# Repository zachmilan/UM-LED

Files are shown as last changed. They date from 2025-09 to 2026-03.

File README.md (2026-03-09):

# UM-LED

UM-LED is a personal embedded systems project I am currently developing. The main idea is to build a cool remote control LED display (in the shape of the University of Michigan's "M") for my desk. This will be done by designing two PCB's - the remote and the display - and writing the firmware for each.

### Project Status 

March 9, 2026: The remote is complete and the firmware is in a consistent working state. Capacitive touch, BLE, haptics, motion detection, sleep timeout, charging and charging indicators, and low battery indicator all function as intended and have been integrated as a system. Changes to the remote's firmware will likely be made once the display is built and integrated, along with a few other polishing touches. Next step is the display PCB schematic. 

This is the first (and hopefully only) version of the remote PCB. Assembly was done using a stencil + hot-plate as well as hand soldering for necessary parts. Some rework and debugging was involved. 

Features, photos, and two short demo videos of the assembled remote exist below.

### Remote Features:
* **Capacitive Touch Pads:** Used for easy brightness control.
* **Accelerometer:** Automatically wakes the remote when picked up.
* **Haptic Motor:** Provides clear tactile feedback for user interactions.
* **USB-C Rechargeable:** Self explanatory, but easily charged with a USB-C cord and indicates charging status via lights.
* **Low Battery Indication:** Red light informs user when remote needs to be charged.
  
| Top View | Bottom View |
| :---: | :---: |
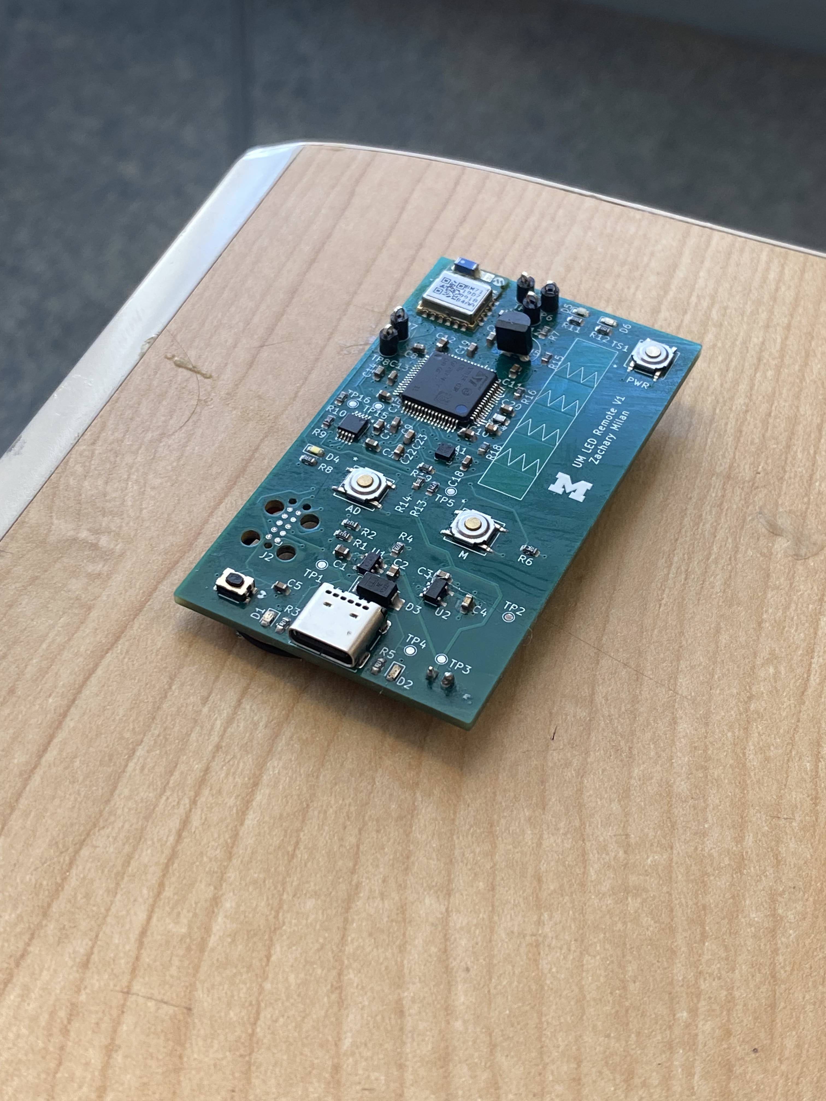
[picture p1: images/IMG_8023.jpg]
UM-LED Remote Top View
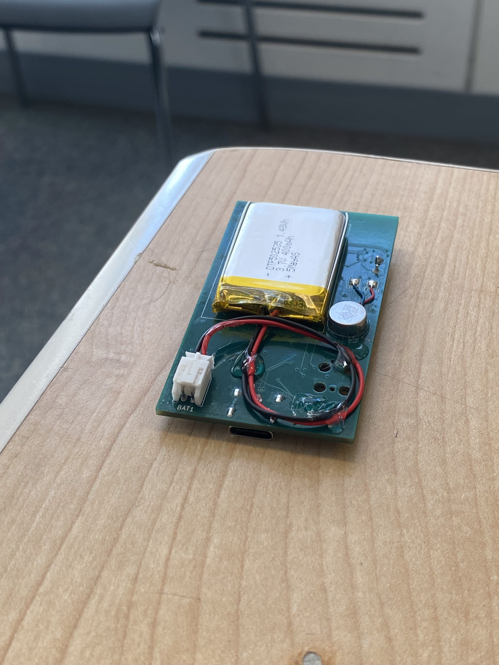
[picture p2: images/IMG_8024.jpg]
UM-LED Remote PCB Detail
|  |  |
| *The top contains the hardware and UI* | *The underside contains the battery and haptic motor (hot-glued)* |

<div align="center">

**Capacitive Touch Demo**

https://github.com/user-attachments/assets/bd866a0d-1efd-45fc-9129-0372a43028ab

*Each touch triggers an LED flash and haptic feedback (turn volume UP to hear haptics firing).*

**Remote Sleep Demo**

https://github.com/user-attachments/assets/c11abb02-e6e1-4325-9b7a-56cc4e109a6d

*The remote wakes upon movement, and falls back asleep after 10 seconds of inactivity.*

</div>

---

### More details
I wrote a full, more formal design proposal when beginning this project — see [UM-LED Design Proposal (PDF)](https://github.com/zachmilan/UM-LED/blob/main/docs/UM-LED%20Design%20Proposal%20(No%20Timeline).pdf). The main idea is still intact, though it may not reflect the full design once done (for example, the accelerometer was an afterthought and hence not included in the proposal).

Or, if you just want to get an idea of the general system architecture, see below: 

| Remote Architecture | Display Architecture |
| :---: | :---: |
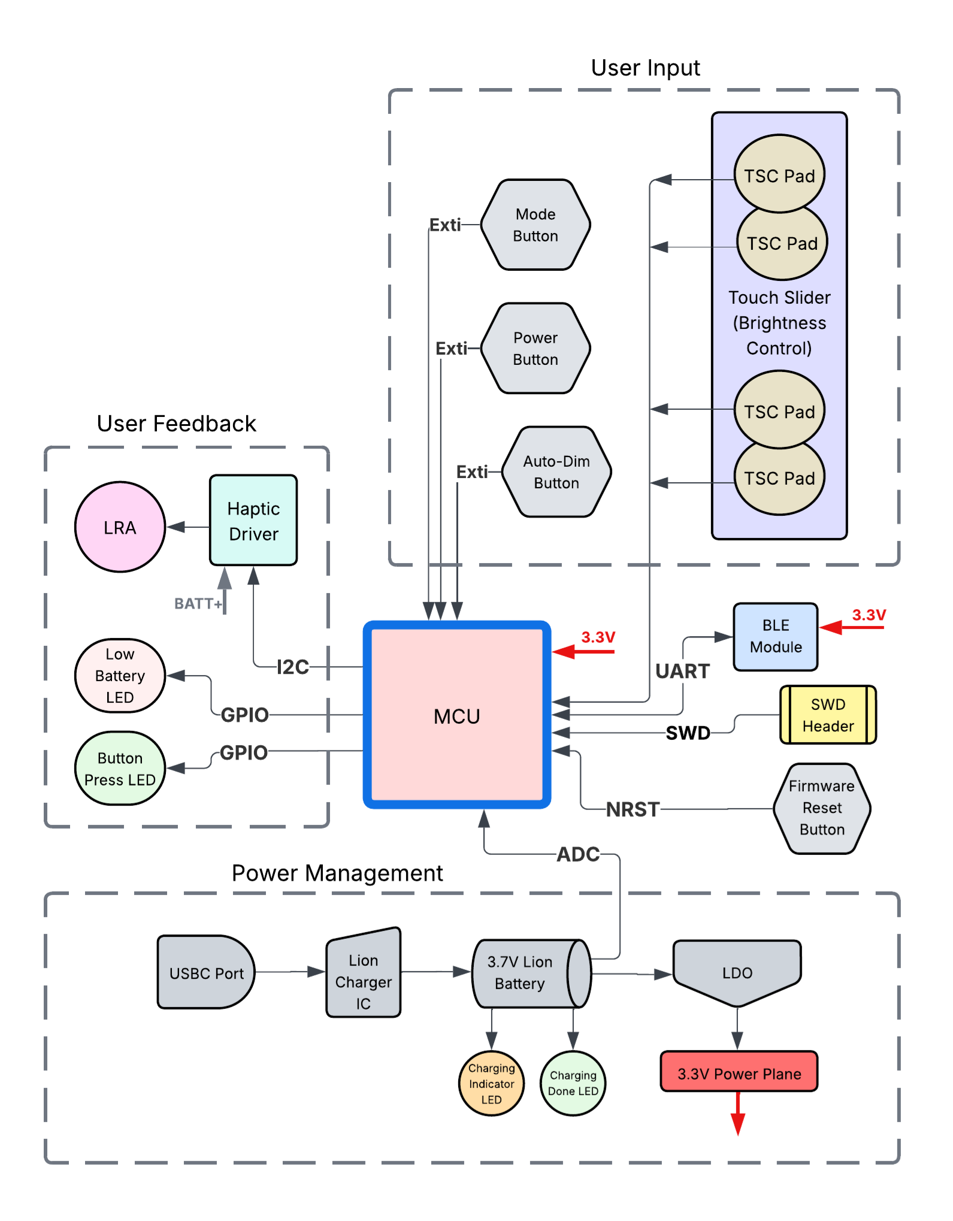
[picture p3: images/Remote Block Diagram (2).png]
UM-LED Remote Architecture
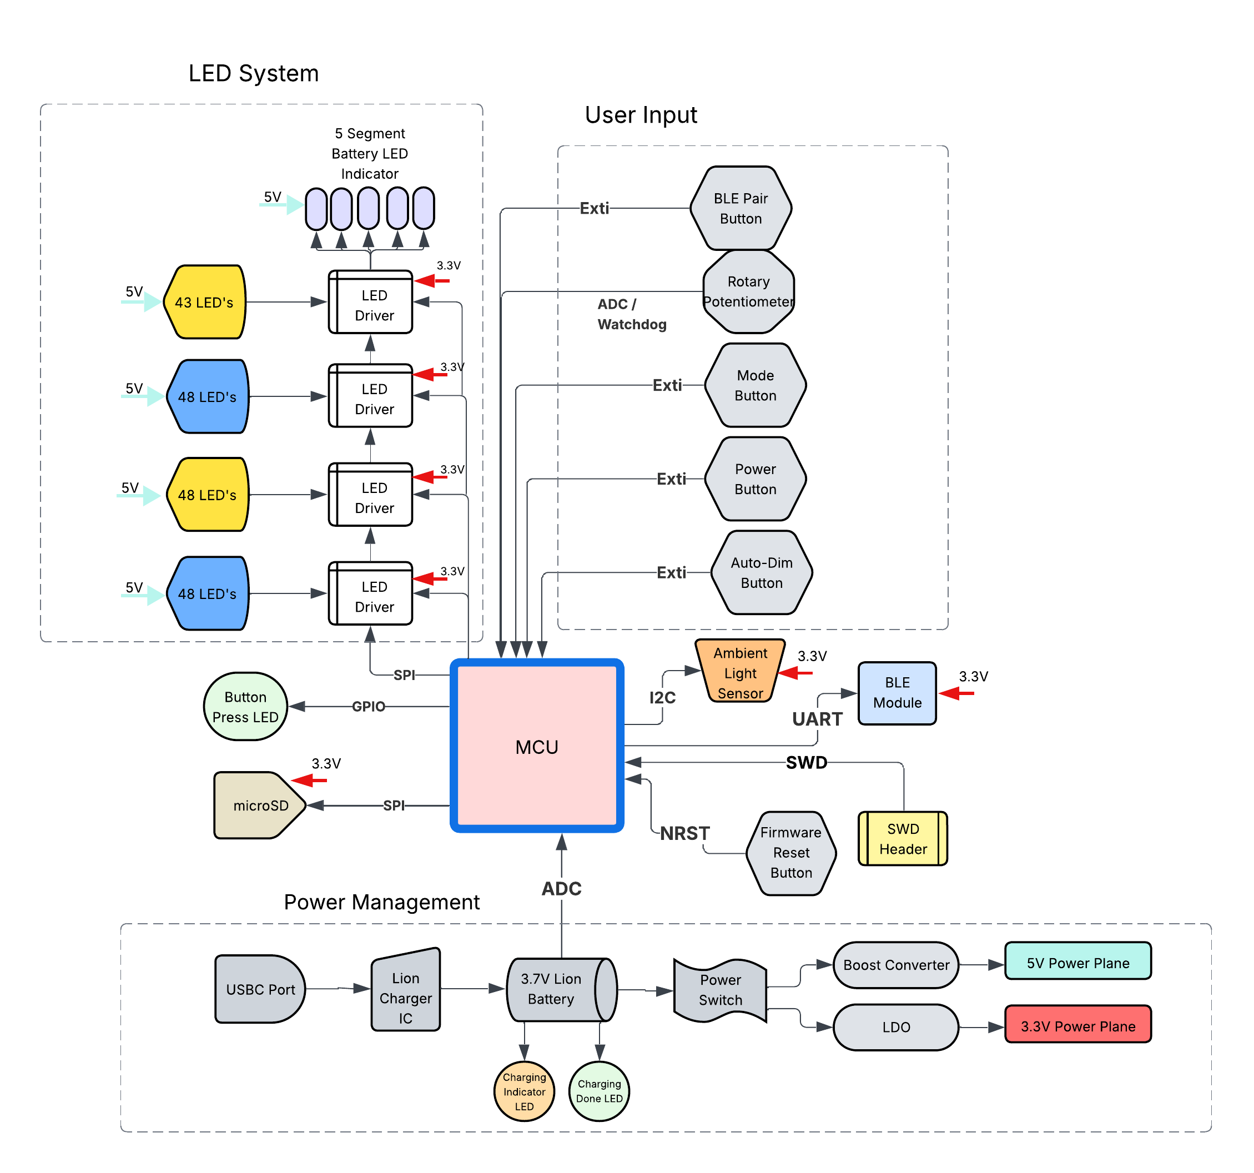
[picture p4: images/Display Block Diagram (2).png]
UM-LED Display Architecture
|  |  |
| *Signal flow for the remote, including the MCU, sensors, and haptic feedback.* | *System architecture for the LED display, including MCU, sensors, and power regulation.* |

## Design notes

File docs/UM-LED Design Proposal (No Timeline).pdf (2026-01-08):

Zachary Milan

UM-LED Design Proposal

This document outlines the planned design and functionality of UM-LED during its early design phase, prior to detailed PCB design, hardware assembly, and firmware implementation. It serves as a proposal for the intended system and the project is subject to change during development.

### 1. Project Overview

UM-LED is a remote-controlled LED display in the shape of the University of Michigan’s Block-M, intended to be a visually striking addition to a room or workspace. The system resembles a consumer product, offering features such as adjustable brightness, multiple LED modes, auto-dimming, and rechargeability. The display rests on a flat surface, supported in an upright position by an attached stand.

The project consists of two parts:

- LED display – a Block-M configuration of individually-controlled LEDs, capable of displaying a variety of patterns with varying brightness.
- Remote Control – a handheld controller with tactile feedback that allows users to wirelessly toggle power, cycle through modes, and adjust brightness of the display.

Together, the display and remote create an interactive device that feels polished, responsive, and fun to use.

### 2. Concept and Purpose

UM-LED is inspired by my pride for the University of Michigan (Go Blue!) and the desire to create something unique for my workspace. At the same time, it serves as a platform to sharpen my embedded systems skills by taking a mere idea through the entire development process, from concept and planning, to PCB schematic and layout, to firmware and mechanical integration, finishing with a polished, consumer-style product.

The design draws from consumer products I admire and use regularly, such as Apple’s use of capacitive touch and haptic feedback, and the simplicity of my rechargeable wireless speaker. These influences shape both the system's interface and the overall user experience.

Figure 1 shows early concept art of UM-LED, illustrating the Block-M display and associated remote, highlighting the consumer-style appearance with simple, intuitive user interfaces for each.

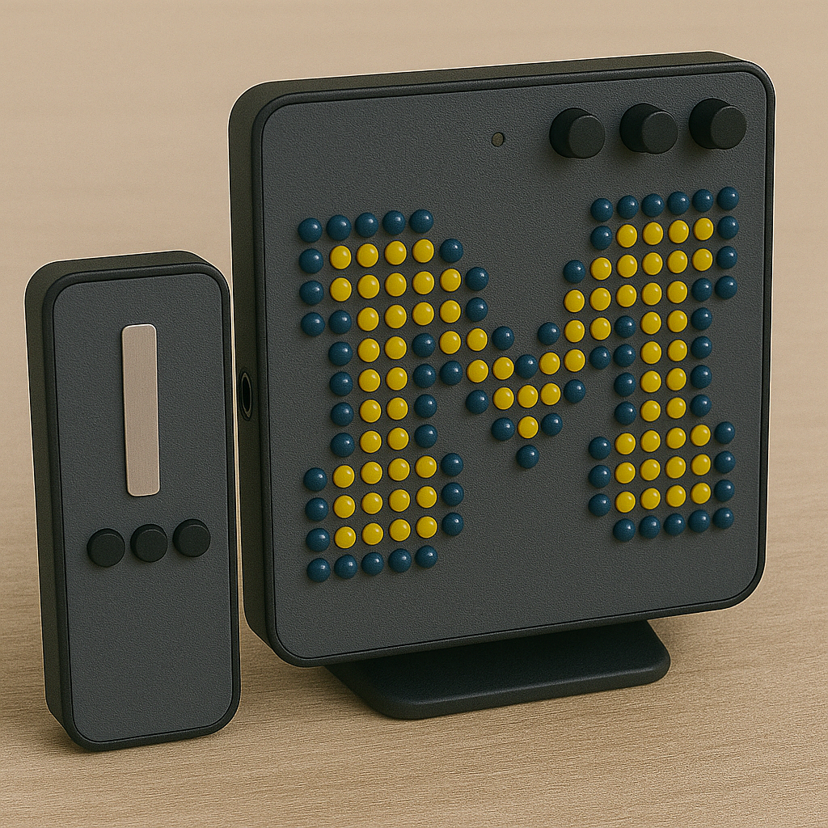
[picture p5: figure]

Figure 1: Rough Concept Art of UM-LED

### 3. System Features

UM-LED includes several features across both the remote and display that enhance the user experience and make the system unique.
Remote Control
- Wireless control of LED display via Bluetooth Low Energy (BLE)
- Brightness control via a capacitive-touch slider
- Haptic feedback upon brightness adjustments
- Mode, power, and auto-dim buttons
- Status indicators for charging, low battery, and button presses
- Rechargeable via USB-C
LED Display
- Through-hole LEDs arranged in the Block-M pattern (yellow fill, blue outline)
- Cyclable LED patterns/modes (heartbeat, snake, demo cycle, etc.)
- Local mode, power, and auto-dim buttons
- Local brightness control via rotating knob
- Status indicators for charging, battery level, auto-dim mode, and button presses
- Rechargeable via USB-C
- A microSD card for logging the display’s power usage over time

### 4. Functional Requirements

UM-LED’s functional requirements are listed below, and are achieved through a combination of component selection, hardware design, and firmware optimizations.
Remote Control
- Recharge time: ≤ 5 hours via USB-C
- Battery life: ≥ 1 week per charge under normal use
- BLE range: 3-5m indoors
- Haptic feedback latency: ≤ 100ms
- Brightness control: ≥ 20 levels
Display
- Recharge time: ≤ 10 hours via USB-C
- Battery life: ≥ 1 week per charge under normal use
- Supports ≥ 5 LED animation modes
- Restores last brightness and mode on startup System Level
- Automatic BLE reconnection after sleep/wake cycle
- Remote inputs update the display within 200ms
- Power usage data is automatically stored when microSD card is present

### 5. System Architecture

The UM-LED system is implemented on two custom printed circuit boards (PCBs) – the display and the remote. Each PCB consists of its own microcontroller, dedicated power system, and necessary peripherals to provide the intended features and functionality.

Remote Architecture
The remote PCB is built around an STM32 microcontroller and integrates multiple user input and feedback features. Brightness is adjusted using a capacitive touch slider implemented through the STM32’s native TSC peripheral, while dedicated tactile pushbuttons provide mode, power, and auto-dim control. A linear resonant actuator (LRA), driven by a haptic driver IC, delivers haptic feedback during brightness adjustments. Wireless communication with the display is handled by a BLE module, and a reset button and SWD header are included for firmware development and debugging. Additional user feedback includes LED indicators for button presses, low battery, and charging status.

Power is supplied by a single-cell 3.7V Li-ion battery, rechargeable via a USB-C receptacle and dedicated charging IC. The battery powers a 3.3V rail – regulated by an LDO – and the haptic driver directly. Figure 2 illustrates the remote’s full architecture.

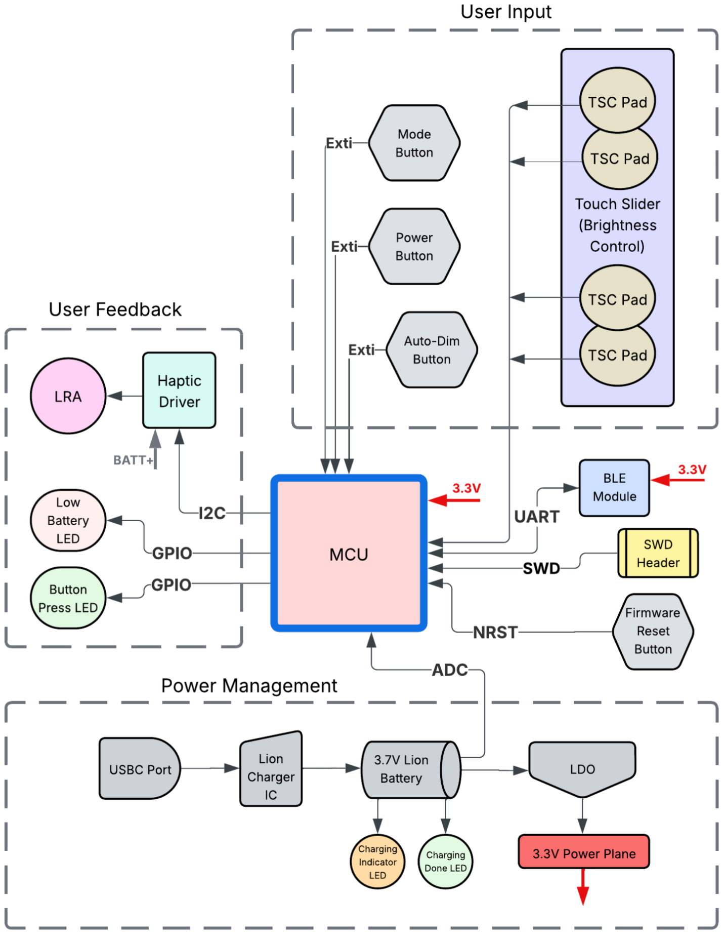
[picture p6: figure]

Figure 2: Remote PCB System Architecture

Display Architecture
The display PCB is built around an STM32 microcontroller and drives the Block-M LED configuration through daisy-chained constant-current LED drivers. Local user input is provided by pushbuttons (mode, power, auto-dim) and a rotary potentiometer for brightness adjustment via ADC readings. An ambient light sensor supports automatic dimming functionality. Wireless control is handled by a BLE module – receiving control data from the remote – and a microSD card slot is included for power-usage logging. A 5-segment LED bar indicates battery status, while other LED indicators exist for button presses and charging status.

Power is supplied by a single-cell 3.7V Li-ion battery, rechargeable via a USB-C receptacle and dedicated charger IC. The battery supplies two voltage rails – a 5V rail via a boost converter (powering the LED configuration), and a 3.3V rail via an LDO for the MCU and peripheral circuitry. A power switch exists to completely cut battery power to the system. Figure 3 illustrates the display’s full architecture.

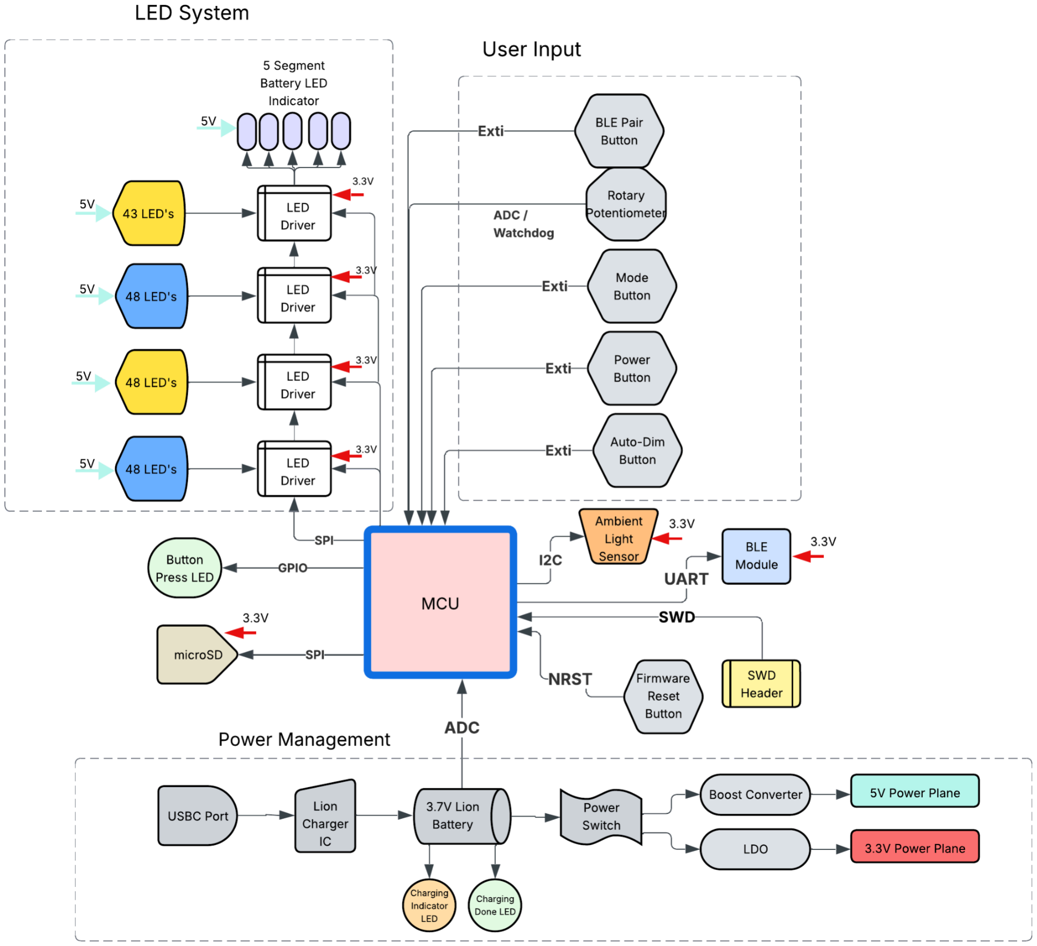
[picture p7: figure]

Figure 3: Display PCB System Architecture

### 7. Major Components

Table 1 lists major components and their functionality and usage across the remote and display boards. Table 1: Major Components

Component | Description & Functionality | Used In
STM32F303RCT6 MCU | Microcontroller for both remote and display boards; chosen for high pin count, built-in TSC peripheral, and variety of serial communication peripherals. | Remote, Display
IS31FL3248 LED Driver | 48-channel constant-current-sink LED driver IC. Chosen for high channel count, SPI interface, and constant-current capability. | Display
BM71BLES1FC2 BLE Module | BLE module for both remote and display. Chosen for its on-board antenna, UART interface, auto-operation feature, and configurable GPIOs. | Remote, Display
DRV2605L Haptic Driver | Haptic driver IC to control LRA for haptic feedback. Chosen for its I2C interface and built-in haptic effects library. | Remote
MCP73831 Linear Charge Controller | Linear charge management controller for remote’s Li-ion battery. Chosen for its simplicity and ease-of-use, as well as programmable charge current and charge status pin. | Remote
MAX77715 Autonomous USB-C Charger | Charge management controller for display’s Li-ion battery. Chosen for its fast charge current, automatic power source detection, and automatic input-current limit configuration. | Display
TLV755P LDO | Low-dropout regulator to supply 3.3V rails. Chosen for its popularity and simplicity, and reliability in a past project. | Remote, Display
MP3432 Boost Converter | Synchronous boost converter to supply 5V rail on the display. Chosen for its capability to output a high amount of current. | Display
VG0832013D LRA | Linear resonant actuator providing haptic feedback on the remote. Chosen for its small profile and popularity. | Remote

### 8. Implementation Details

Remote Firmware
Capacitive Touch Slider – The STM32’s TSC peripheral samples touch pads simultaneously. Values are smoothed/averaged, extreme readings mitigated, and the final result mapped to a discrete brightness level.

Buttons – Mode, power, auto-dim buttons generate interrupts upon press. Button debouncing and long-press detection occur in software.

Haptic Feedback – A linear resonant actuator (LRA) is driven by a dedicated haptic driver IC, controlled by the STM32 via I2C and a TRIG pin. The TRIG pin activates a predetermined haptic effect, occurring in sync with brightness changes sent over BLE.

BLE – The BLE modules function in “Auto-Operation” mode, acting as a UART bridge between boards for transmitting control data such as brightness, mode, auto-dim, and power.
Display Firmware
LED Control – The LED drivers are initialized and controlled via SPI. Each of the driver’s 48 channels is controlled individually via PWM registers, allowing for flexible patterns and a wide range of brightness. Multiple drivers are daisy-chained to support a high number of LEDs. Additionally, enabling the BLANK pin allows for immediate shutoff of all LEDs connected to a driver.

Local Controls – Similar to the remote, buttons on the display provide user access to mode, power, and auto-dim controls and generate interrupts upon press. Button debouncing and long-press detection occur in software. For brightness control, a rotary potentiometer provides an analog input, which firmware maps to a brightness scale for the display.

Ambient Light Sensor – In auto-dim mode, the display periodically takes readings from an ambient light sensor and updates global LED brightness accordingly.
Power Management
MCU Sleep/Wake – Both boards utilize low-power or sleep modes when idle, and wake upon user input or BLE events.

Battery Indicators – Voltage readings of the battery are taken via ADC. Firmware compares readings to determined thresholds and updates the display’s 5-segment bar or remote’s low-battery LED accordingly.

Charging – Charging ICs on both the remote and display handle safe battery charging without the need for firmware intervention.
Programming & Configuration
MCU Programming – The STM32 on both boards are programmed via SWD. Each board exposes SWD pins through a footprint compatible with a Tag-Connect cable connected to a ST-Link programmer.

BLE Configuration – The BLE modules are configured through UART using Microchip’s PC GUI tool. Low-profile test loops are provided on both boards to provide programming access for the module.

### 9. Proposed Physical Design

The proposed physical design of both the remote and display establishes the placement of user-interface elements in order to support preliminary STM32 pin-mapping and simplify PCB routing. These illustrations do not include all major components listed in Table 1, but emphasize user-interface and feedback elements that are given priority for pin assignments. Figures 4 and 5 illustrate the physical layout of the remote and display.

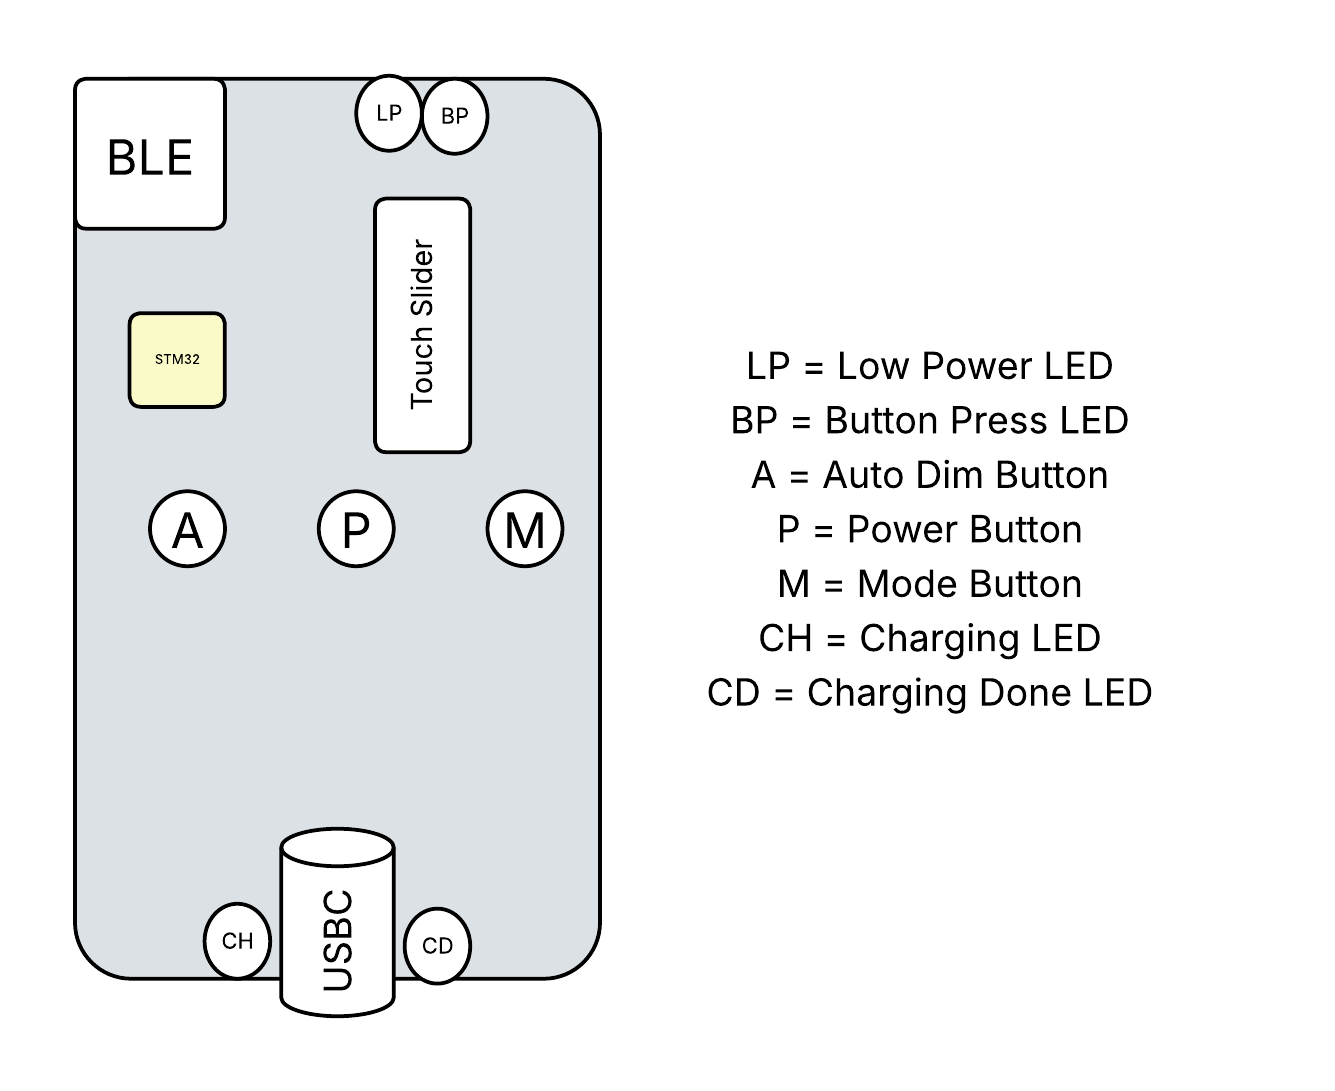
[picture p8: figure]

Figure 4: Remote Physical Layout

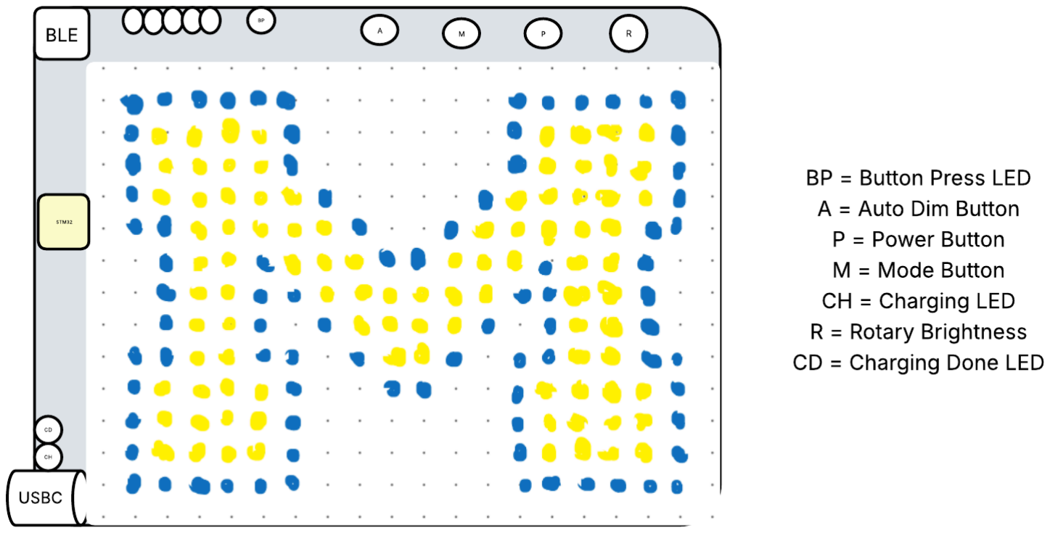
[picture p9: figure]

Figure 5: Display Physical Layout

### 10. Anticipated Technical Challenges

UM-LED involves several technical hurdles spanning hardware, firmware, wireless communication, and mechanical design. Table 2 details anticipated technical challenges along with a brief description of each. Table 2: Technical Challenges

Technical Challenge | Description
LED Driver Thermal Management | Managing heat dissipation from multiple constant-current LED drivers under high load (stemming from high brightness levels).
Switching Noise Suppression | Reducing switching noise from the boost converter and LED drivers on the display, which could interfere with serial communication and affect power integrity.
Reliable Wireless Communication | Ensuring automatic BLE reconnection between remote and display after waking, and achieving low-latency responses between remote user input and a display update.
Capacitive Touch Algorithm | Developing firmware to translate readings from a limited number of touch pads to numerous brightness levels and avoiding sudden jumps to extreme values.
MCU Power Management | Designing an efficient sleep/wake control flow for both boards in order to balance responsiveness during use with extended battery life when idle.
Power Logging to microSD Card | Implementing accurate and reliable logging of power usage data, including determining an appropriate sampling frequency and logging duration.
Mechanical Integration | Designing and producing polished 3D enclosures for both boards that expose the user interface and hide internal hardware.

### 11. Stretch Goals / Future Development

UM-LED has potential for several upgrades once the base system is complete. Extended functionality can be implemented through firmware updates, additional hardware, or both. Table 3 details possible stretch goals and a description for each.
Table 3: Stretch Goals
Stretch Goal | Description
Mobile Companion App | Develop a mobile app to control the display over BLE, offering an alternative to the physical remote and enabling extended control functionality.
Audio-sensitive LEDs | Add hardware and firmware to allow the display to react dynamically to ambient sound.
Battery Percentage Estimation | Provide a precise battery percentage readout on the display, potentially via a small LCD or OLED, instead of a 5-segment LED bar.
Extended Capacitive Slider Functions | Enable the remote’s capacitive slider to perform different actions depending on the mode (e.g. brightness adjustment and direct LED control)
Improved Mounting Options | Develop solutions for flexible mounting, such as wall brackets or magnetic attachments, in addition to the default stand.

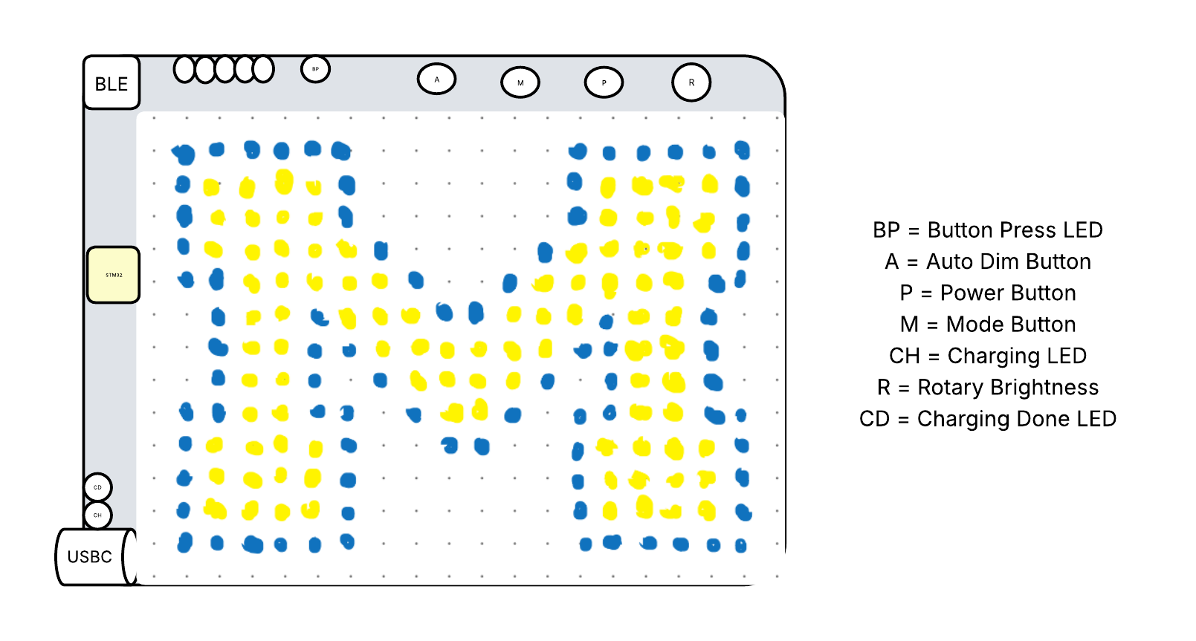
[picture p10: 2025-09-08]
images/Display Layout.png

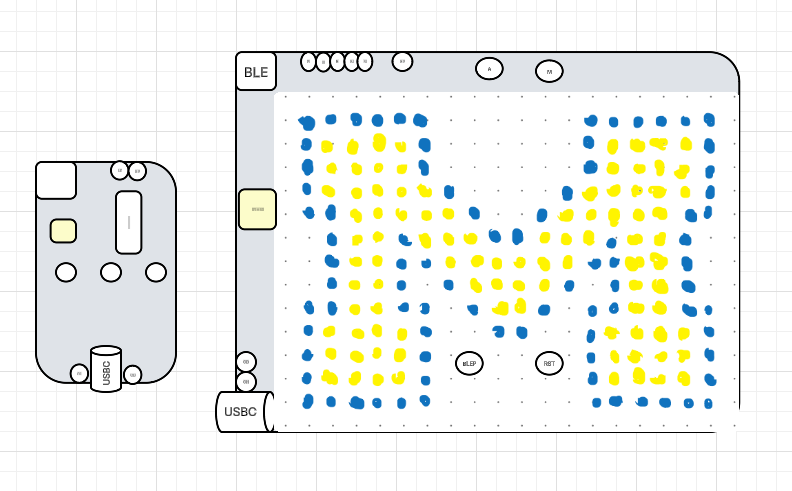
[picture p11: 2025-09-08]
images/Screenshot 2025-09-07 221949.png

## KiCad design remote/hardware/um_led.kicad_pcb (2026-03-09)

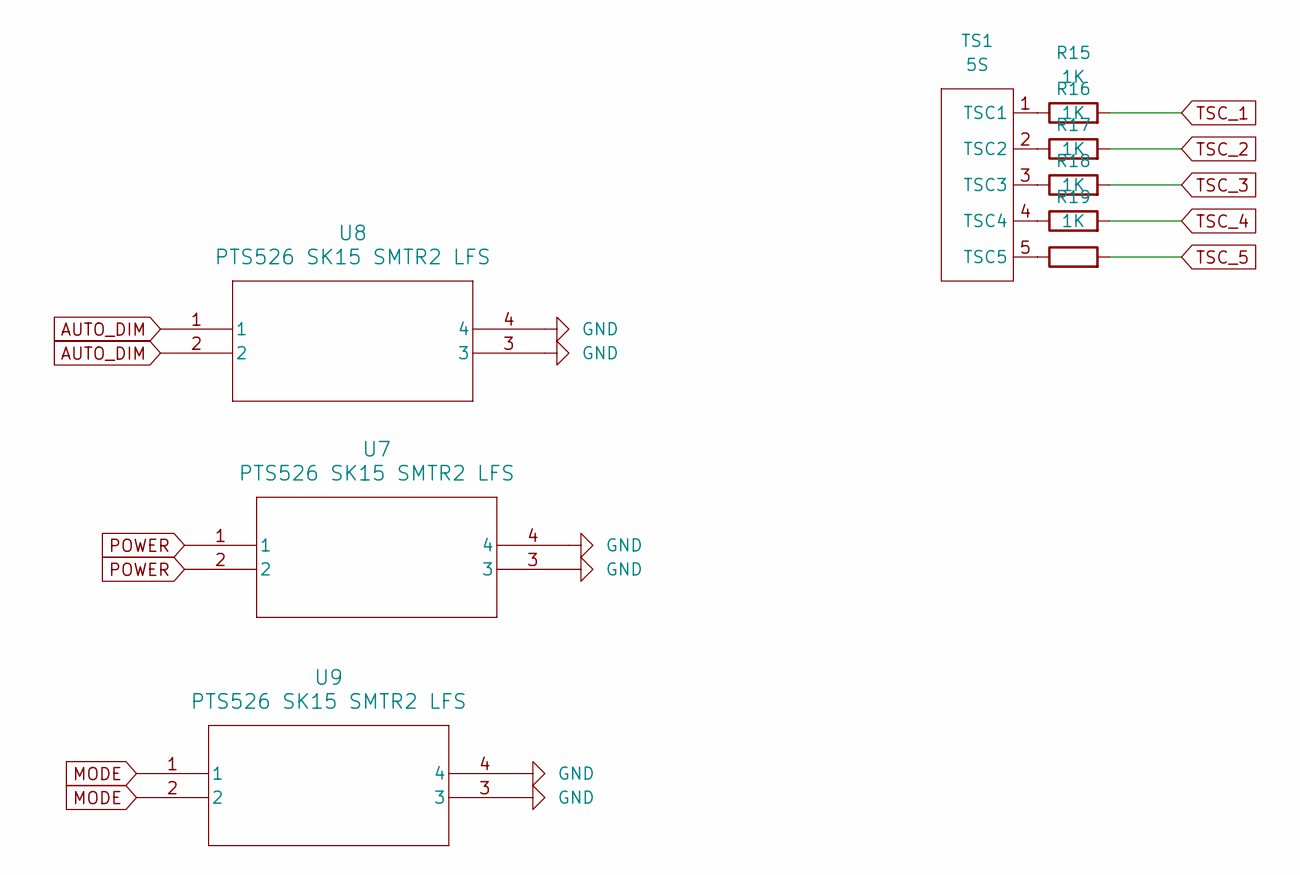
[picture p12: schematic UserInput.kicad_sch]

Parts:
R15, R16, R17, R18, R19: 1K; R_0603_1608Metric
TS1: 5S; TouchSlider-5_30x6mm
U7, U8, U9: PTS526 SK15 SMTR2 LFS; SMT_FS

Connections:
AUTO_DIM: U8.1, U8.2; also elsewhere on the board
GND: U7.3, U7.4, U8.3, U8.4, U9.3, U9.4; also elsewhere on the board
MODE: U9.1, U9.2; also elsewhere on the board
unnamed: R15.1, TS1.1 (TSC1)
unnamed: R16.1, TS1.2 (TSC2)
unnamed: R17.1, TS1.3 (TSC3)
unnamed: R18.1, TS1.4 (TSC4)
unnamed: R19.1, TS1.5 (TSC5)
POWER: U7.1, U7.2; also elsewhere on the board
TSC_1: R15.2; also elsewhere on the board
TSC_2: R16.2; also elsewhere on the board
TSC_3: R17.2; also elsewhere on the board
TSC_4: R18.2; also elsewhere on the board
TSC_5: R19.2; also elsewhere on the board

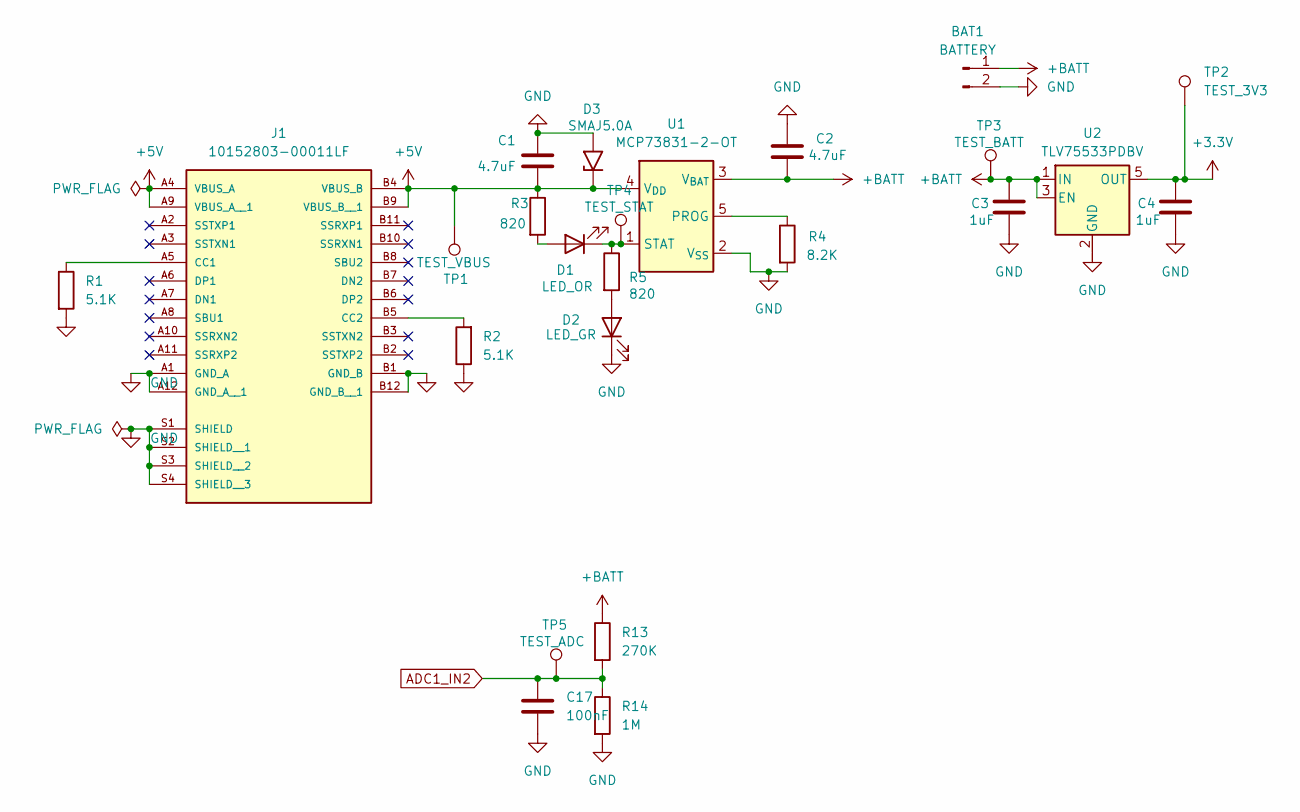
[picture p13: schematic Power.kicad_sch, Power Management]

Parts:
BAT1: BATTERY; JST_PH_S2B-PH-K_1x02_P2.00mm_Horizontal
C1, C2: 4.7uF; C_0603_1608Metric
C3, C4: 1uF; C_0603_1608Metric
C17: 100nF; C_0603_1608Metric
D1: LED_OR; LED_0603_1608Metric
D2: LED_GR; LED_0603_1608Metric
D3: SMAJ5.0A; D_SMA
J1: 10152803-00011LF; AMPHENOL_10152803-00011LF; PARTREV A
R1, R2: 5.1K; R_0603_1608Metric
R3, R5: 820; R_0603_1608Metric
R4: 8.2K; R_0603_1608Metric
R13: 270K; R_0603_1608Metric
R14: 1M; R_0603_1608Metric
TP1: TEST_VBUS; TestPoint_Pad_D1.0mm
TP2: TEST_3V3; TestPoint_Pad_D1.0mm
TP3: TEST_BATT; TestPoint_Pad_D1.0mm
TP4: TEST_STAT; TestPoint_Pad_D1.0mm
TP5: TEST_ADC; TestPoint_Pad_D1.0mm
U1: MCP73831-2-OT; SOT-23-5
U2: TLV75533PDBV; SOT-23-5

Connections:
+3.3V: C4.1, TP2.1, U2.5 (OUT); also elsewhere on the board
+5V: C1.2, D3.1 (A1), J1.A4 (VBUS_A), J1.A9 (VBUS_A__1), J1.B4 (VBUS_B), J1.B9 (VBUS_B__1), R3.1, TP1.1, U1.4 (V_{DD})
+BATT: BAT1.1, C2.2, C3.1, R13.1, TP3.1, U1.3 (V_{BAT}), U2.1 (IN), U2.3 (EN); also elsewhere on the board
ADC1_IN2: C17.1, R13.2, R14.1, TP5.1; also elsewhere on the board
GND: BAT1.2, C1.1, C2.1, C3.2, C4.2, C17.2, D2.1 (K), D3.2 (A2), J1.A1 (GND_A), J1.A12 (GND_A__1), J1.B1 (GND_B), J1.B12 (GND_B__1), J1.S1 (SHIELD), J1.S2 (SHIELD__1), J1.S3 (SHIELD__2), J1.S4 (SHIELD__3), R1.2, R2.1, R4.2, R14.2, U1.2 (V_{SS}), U2.2 (GND); also elsewhere on the board
unnamed: D1.2 (A), R3.2
unnamed: D1.1 (K), R5.1, TP4.1, U1.1 (STAT)
unnamed: D2.2 (A), R5.2
unnamed: J1.A5 (CC1), R1.1
unnamed: J1.B5 (CC2), R2.2
unnamed: R4.1, U1.5 (PROG)

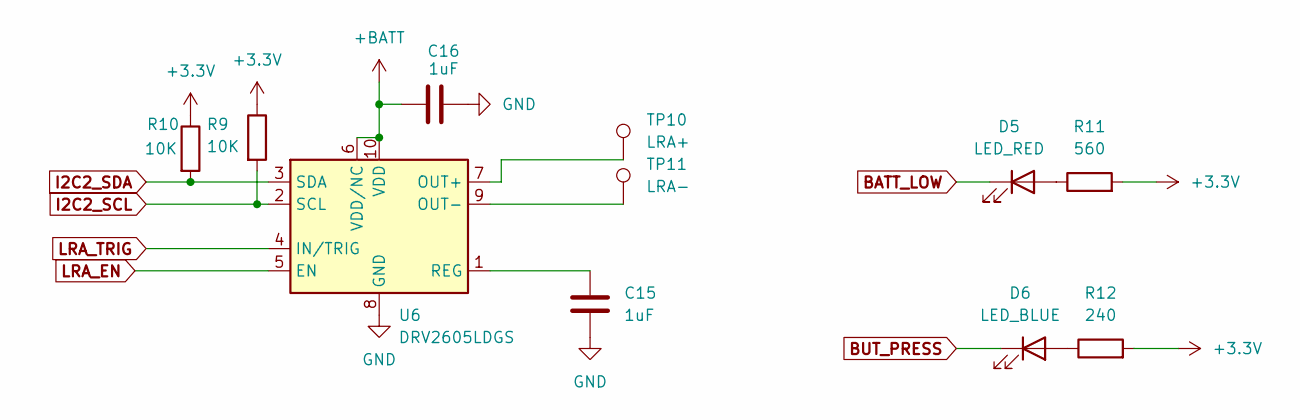
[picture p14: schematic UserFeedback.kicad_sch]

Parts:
C15, C16: 1uF; C_0603_1608Metric
D5: LED_RED; LED_0603_1608Metric
D6: LED_BLUE; LED_0603_1608Metric
R9, R10: 10K; R_0603_1608Metric
R11: 560; R_0603_1608Metric
R12: 240; R_0603_1608Metric
TP10: LRA+; TestPoint_Pad_2.0x2.0mm
TP11: LRA-; TestPoint_Pad_2.0x2.0mm
U6: DRV2605LDGS; VSSOP-10_3x3mm_P0.5mm

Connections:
+3.3V: R9.1, R10.1, R11.2, R12.2; also elsewhere on the board
+BATT: C16.2, U6.6 (VDD/NC), U6.10 (VDD); also elsewhere on the board
BATT_LOW: D5.1 (K); also elsewhere on the board
BUT_PRESS: D6.1 (K); also elsewhere on the board
GND: C15.1, C16.1, U6.8 (GND); also elsewhere on the board
I2C2_SCL: R9.2, U6.2 (SCL); also elsewhere on the board
I2C2_SDA: R10.2, U6.3 (SDA); also elsewhere on the board
LRA_EN: U6.5 (EN); also elsewhere on the board
LRA_TRIG: U6.4 (IN/TRIG); also elsewhere on the board
unnamed: D5.2 (A), R11.1
unnamed: D6.2 (A), R12.1
unnamed: TP10.1, U6.7 (OUT+)
unnamed: TP11.1, U6.9 (OUT-)
unnamed: C15.2, U6.1 (REG)

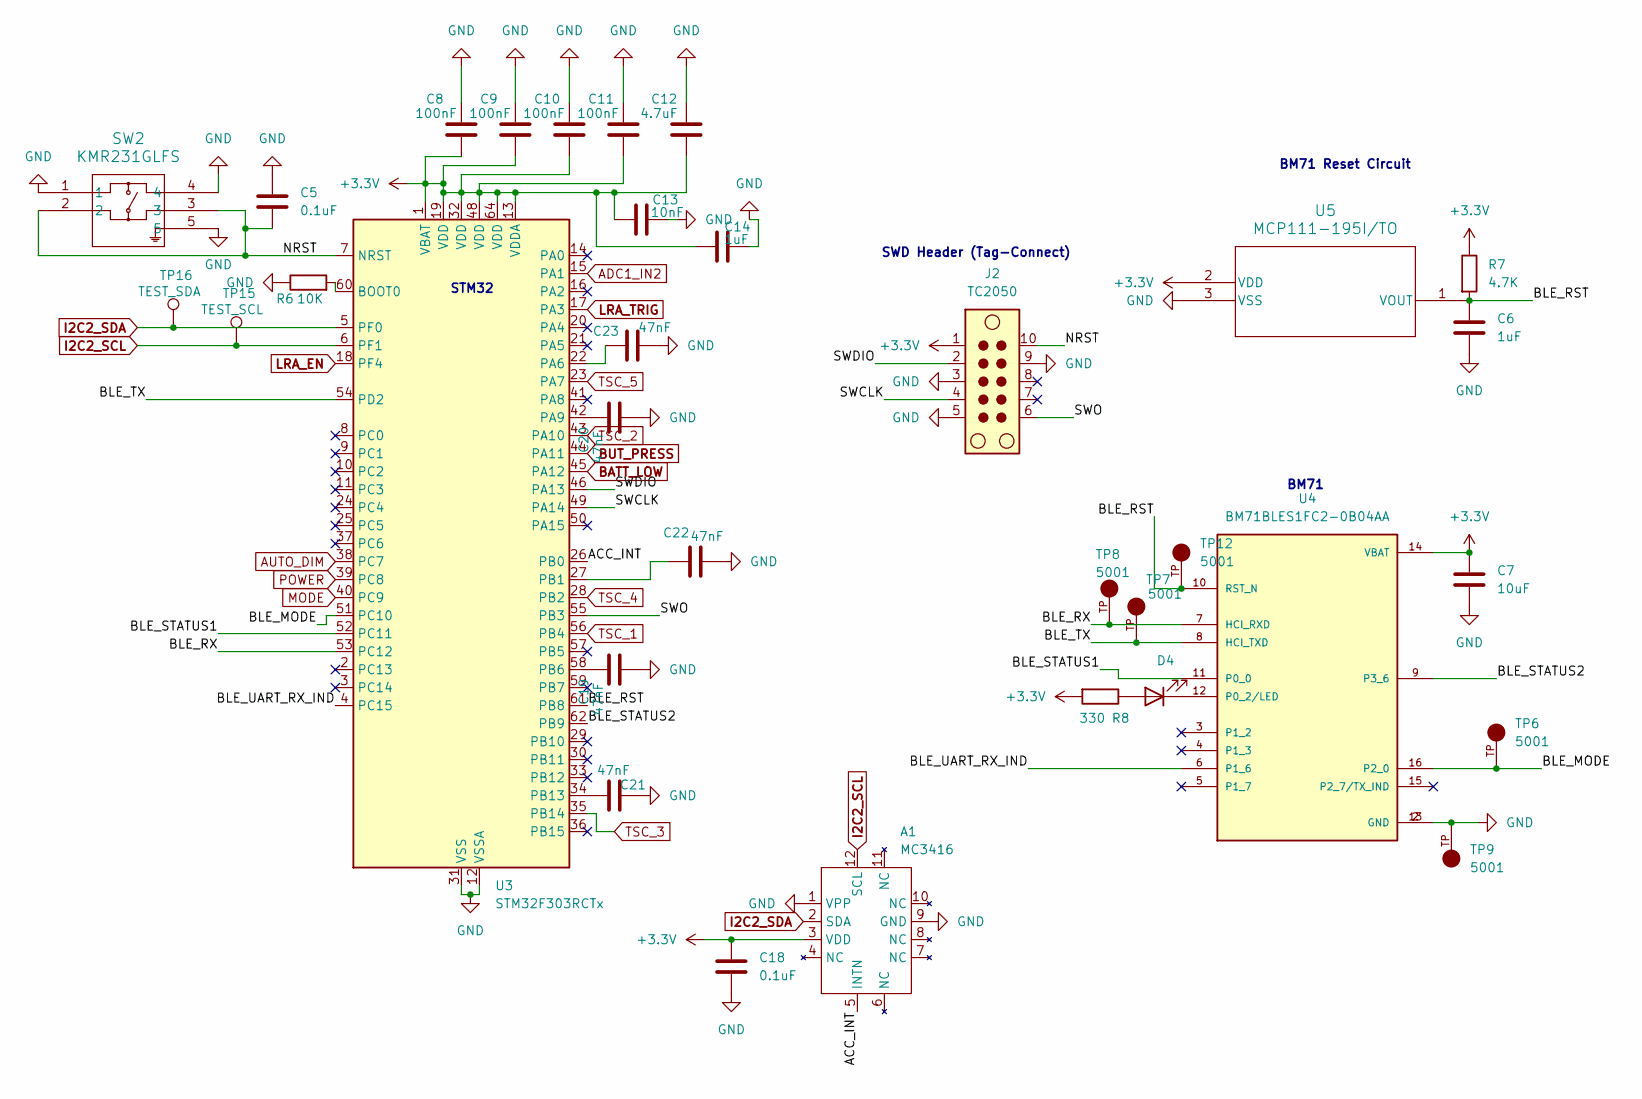
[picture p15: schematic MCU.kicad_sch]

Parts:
A1: MC3416; LGA-12_2x2mm_P0.5mm
C5, C18: 0.1uF; C_0603_1608Metric
C6, C14: 1uF; C_0603_1608Metric
C7: 10uF; C_0603_1608Metric
C8, C9, C10, C11: 100nF; C_0603_1608Metric
C12: 4.7uF; C_0603_1608Metric
C13: 10nF; C_0603_1608Metric
C19, C20, C21, C22, C23: 47nF; C_0603_1608Metric
D4: LED_WHITE; LED_0603_1608Metric
J2: TC2050; Tag-Connect_TC2050-IDC-FP_2x05_P1.27mm_Vertical
R6: 10K; R_0603_1608Metric
R7: 4.7K; R_0603_1608Metric
R8: 330; R_0603_1608Metric
SW2: KMR231GLFS; KMR2xxG_CNK
TP6, TP7, TP8, TP9, TP12: 5001; KEYSTONE_5001; PARTREV H; DigiKey_Part_Number 36-5001-ND
TP15: TEST_SCL; TestPoint_Pad_D1.0mm
TP16: TEST_SDA; TestPoint_Pad_D1.0mm
U3: STM32F303RCTx; LQFP-64_10x10mm_P0.5mm
U4: BM71BLES1FC2-0B04AA; XCVR_BM71BLES1FC2-0B04AA
U5: MCP111-195I/TO; TO-92_MC_MCH

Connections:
+3.3V: A1.3 (VDD), C7.1, C8.2, C9.2, C10.2, C11.2, C12.2, C13.1, C14.1, C18.1, J2.1, R7.1, R8.2, U3.1 (VBAT), U3.13 (VDDA), U3.19 (VDD), U3.32 (VDD), U3.48 (VDD), U3.64 (VDD), U4.14 (VBAT), U5.2 (VDD); also elsewhere on the board
/MCU/ACC_INT: A1.5 (INTN), U3.26 (PB0)
/MCU/BLE_MODE: TP6.TP, U3.51 (PC10), U4.16 (P2_0)
/MCU/BLE_RST: C6.1, R7.2, TP12.TP, U3.61 (PB8), U4.10 (RST_N), U5.1 (VOUT)
/MCU/BLE_RX: TP8.TP, U3.53 (PC12), U4.7 (HCI_RXD)
/MCU/BLE_STATUS1: U3.52 (PC11), U4.11 (P0_0)
/MCU/BLE_STATUS2: U3.62 (PB9), U4.9 (P3_6)
/MCU/BLE_TX: TP7.TP, U3.54 (PD2), U4.8 (HCI_TXD)
/MCU/BLE_UART_RX_IND: U3.4 (PC15), U4.6 (P1_6)
/MCU/NRST: C5.2, J2.10, SW2.2, SW2.3, U3.7 (NRST)
/MCU/SWCLK: J2.4, U3.49 (PA14)
/MCU/SWDIO: J2.2, U3.46 (PA13)
/MCU/SWO: J2.6, U3.55 (PB3)
ADC1_IN2: U3.15 (PA1); also elsewhere on the board
AUTO_DIM: U3.38 (PC7); also elsewhere on the board
BATT_LOW: U3.45 (PA12); also elsewhere on the board
BUT_PRESS: U3.44 (PA11); also elsewhere on the board
GND: A1.1 (VPP), A1.9 (GND), C5.1, C6.2, C7.2, C8.1, C9.1, C10.1, C11.1, C12.1, C13.2, C14.2, C18.2, C19.2, C20.2, C21.2, C22.2, C23.2, J2.3, J2.5, J2.9, R6.1, SW2.1, SW2.4, SW2.5, TP9.TP, U3.12 (VSSA), U3.31 (VSS), U3.47 (VSS), U3.63 (VSS), U4.2 (GND), U4.13 (GND), U5.3 (VSS); also elsewhere on the board
I2C2_SCL: A1.12 (SCL), TP15.1, U3.6 (PF1); also elsewhere on the board
I2C2_SDA: A1.2 (SDA), TP16.1, U3.5 (PF0); also elsewhere on the board
LRA_EN: U3.18 (PF4); also elsewhere on the board
LRA_TRIG: U3.17 (PA3); also elsewhere on the board
MODE: U3.40 (PC9); also elsewhere on the board
unnamed: D4.2 (A), R8.1
unnamed: D4.1 (K), U4.12 (P0_2/LED)
unnamed: R6.2, U3.60 (BOOT0)
unnamed: C23.1, U3.22 (PA6)
unnamed: C20.1, U3.42 (PA9)
unnamed: C22.1, U3.27 (PB1)
unnamed: C19.1, U3.58 (PB6)
unnamed: C21.1, U3.34 (PB13)
POWER: U3.39 (PC8); also elsewhere on the board
TSC_1: U3.56 (PB4); also elsewhere on the board
TSC_2: U3.43 (PA10); also elsewhere on the board
TSC_3: U3.35 (PB14); also elsewhere on the board
TSC_4: U3.28 (PB2); also elsewhere on the board
TSC_5: U3.23 (PA7); also elsewhere on the board

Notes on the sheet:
SWD Header (Tag-Connect)
STM32
BM71
BM71 Reset Circuit

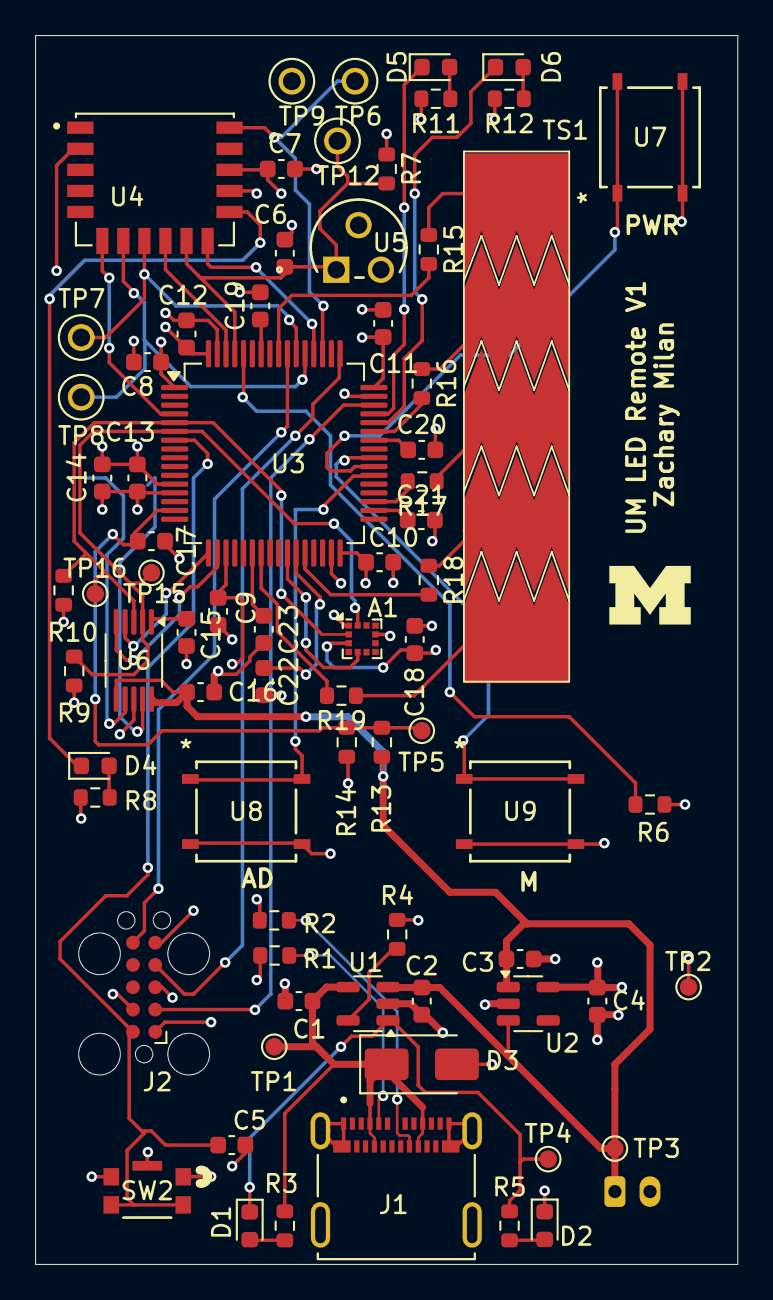
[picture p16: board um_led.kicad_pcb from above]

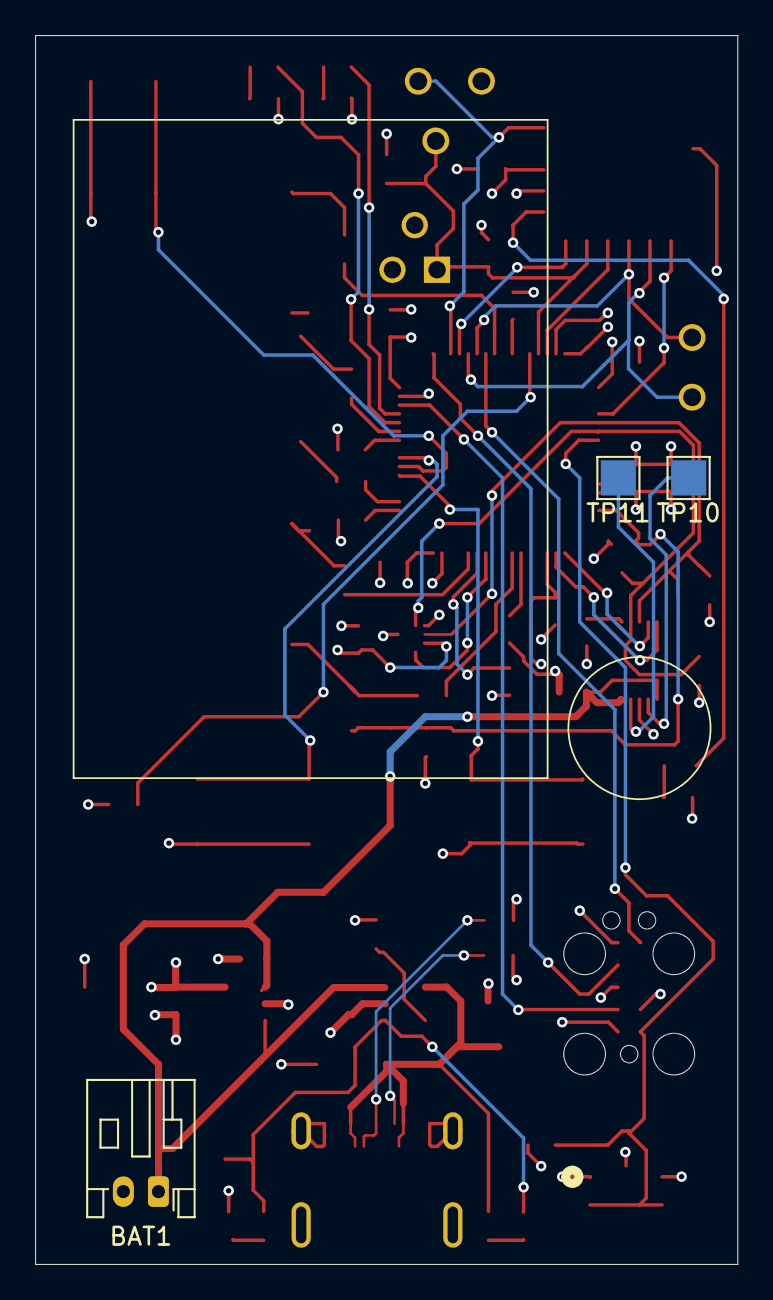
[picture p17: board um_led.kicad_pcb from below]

Board: 4 copper layers, 40.0 x 70.0 mm, 77 parts (3 on the bottom side), 55 nets.

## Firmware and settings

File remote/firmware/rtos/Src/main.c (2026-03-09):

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
/* Includes ------------------------------------------------------------------*/
#include "main.h"
#include "cmsis_os.h"
#include "touchsensing.h"

/* USER CODE BEGIN Includes */
#include <stdio.h>
#include "tsl_user.h"
#include "drv2605l.h"
#include "mc3416.h"
#include <stdbool.h>
#include "math.h"
#include "stdlib.h"
#include "led.h"
#include "slider.h"
#include "bm71.h"
/* USER CODE END Includes */

/* USER CODE BEGIN PTD */
typedef enum {
	NONE,
	MODE,
	AUTODIM,
	POWER
} button_t;
/* USER CODE END PTD */

ADC_HandleTypeDef hadc1;

I2C_HandleTypeDef hi2c2;

TSC_HandleTypeDef htsc;

UART_HandleTypeDef huart5;

/* Definitions for mainTask */
osThreadId_t mainTaskHandle;
const osThreadAttr_t mainTask_attributes = {
  .name = "mainTask",
  .stack_size = 300 * 4,
  .priority = (osPriority_t) osPriorityNormal,
};
/* Definitions for buttonTask */
osThreadId_t buttonTaskHandle;
const osThreadAttr_t buttonTask_attributes = {
  .name = "buttonTask",
  .stack_size = 64 * 4,
  .priority = (osPriority_t) osPriorityNormal5,
};
/* Definitions for uartTask */
osThreadId_t uartTaskHandle;
const osThreadAttr_t uartTask_attributes = {
  .name = "uartTask",
  .stack_size = 128 * 4,
  .priority = (osPriority_t) osPriorityNormal3,
};
/* Definitions for I2C2_lock */
osMutexId_t I2C2_lockHandle;
const osMutexAttr_t I2C2_lock_attributes = {
  .name = "I2C2_lock"
};
/* Definitions for blueLedLock */
osMutexId_t blueLedLockHandle;
const osMutexAttr_t blueLedLock_attributes = {
  .name = "blueLedLock"
};
/* Definitions for bm71Lock */
osMutexId_t bm71LockHandle;
const osMutexAttr_t bm71Lock_attributes = {
  .name = "bm71Lock"
};
/* Definitions for buttonPressSem */
osSemaphoreId_t buttonPressSemHandle;
const osSemaphoreAttr_t buttonPressSem_attributes = {
  .name = "buttonPressSem"
};
/* Definitions for uartRecSem */
osSemaphoreId_t uartRecSemHandle;
const osSemaphoreAttr_t uartRecSem_attributes = {
  .name = "uartRecSem"
};
/* USER CODE BEGIN PV */
uint32_t currentTime;
uint32_t previousTime = 0;
volatile uint32_t lastActivity = 0;
uint32_t lastPwrPress = 0;
uint32_t lastModePress = 0;
uint32_t lastAutoDimPress = 0;
uint32_t lastMotion = 0;
uint32_t bleResetTime = 0;
uint32_t lastBattCheck = 0;
volatile bool modePressed = false;
volatile bool autoDimPresssed = false;
volatile bool pwrPressed = false;
volatile button_t buttonPressed = NONE; // in future, use flag/mask. for now this is fine as button presses are sparse
volatile bool toggleBlueActive;
/* USER CODE END PV */

void SystemClock_Config(void);
static void MX_GPIO_Init(void);
static void MX_TSC_Init(void);
static void MX_ADC1_Init(void);
static void MX_I2C2_Init(void);
static void MX_UART5_Init(void);
void StartMainTask(void *argument);
void StartButtonTask(void *argument);
void StartUartRecTask(void *argument);

/**
  * @brief  The application entry point.
  * @retval int
  */
int main(void)
{
  /* USER CODE BEGIN 1 */
//	printf("here!\n"); // avoid printf in RTOS
  /* USER CODE END 1 */

  /* MCU Configuration--------------------------------------------------------*/

  /* Reset of all peripherals, Initializes the Flash interface and the Systick. */
  HAL_Init();

  /* Configure the system clock */
  SystemClock_Config();

  /* Initialize all configured peripherals */
  MX_GPIO_Init();
  MX_TSC_Init();
  MX_ADC1_Init();
  MX_I2C2_Init();
  MX_TOUCHSENSING_Init();
  MX_UART5_Init();
  /* USER CODE BEGIN 2 */

  // ---------- USER PERIPHERAL INIT BEGIN ------------
  BM71_Init(&huart5);
  DRV2605L_Init(&hi2c2);
  DRV2605L_SequenceWaveform(7, 1);
  MC3416_Init(&hi2c2);
  // ---------- USER PERIPHERAL INIT END ------------

//  DRV2605L_SequenceWaveform(7, 1);
//  BM71_ReadDeviceName();
  /* USER CODE END 2 */

  /* Init scheduler */
  osKernelInitialize();
  /* Create the mutex(es) */
  /* creation of I2C2_lock */
  I2C2_lockHandle = osMutexNew(&I2C2_lock_attributes);

  /* creation of blueLedLock */
  blueLedLockHandle = osMutexNew(&blueLedLock_attributes);

  /* creation of bm71Lock */
  bm71LockHandle = osMutexNew(&bm71Lock_attributes);

  /* USER CODE BEGIN RTOS_MUTEX */
  /* add mutexes, ... */
  /* USER CODE END RTOS_MUTEX */

  /* Create the semaphores(s) */
  /* creation of buttonPressSem */
  buttonPressSemHandle = osSemaphoreNew(1, 0, &buttonPressSem_attributes);

  /* creation of uartRecSem */
  uartRecSemHandle = osSemaphoreNew(1, 0, &uartRecSem_attributes);

  /* USER CODE BEGIN RTOS_SEMAPHORES */
  /* add semaphores, ... */
  /* USER CODE END RTOS_SEMAPHORES */

  /* USER CODE BEGIN RTOS_TIMERS */
  /* start timers, add new ones, ... */
  /* USER CODE END RTOS_TIMERS */

  /* USER CODE BEGIN RTOS_QUEUES */
  /* add queues, ... */
  /* USER CODE END RTOS_QUEUES */

  /* Create the thread(s) */
  /* creation of mainTask */
  mainTaskHandle = osThreadNew(StartMainTask, NULL, &mainTask_attributes);

  /* creation of buttonTask */
  buttonTaskHandle = osThreadNew(StartButtonTask, NULL, &buttonTask_attributes);

  /* creation of uartTask */
  uartTaskHandle = osThreadNew(StartUartRecTask, NULL, &uartTask_attributes);

  /* USER CODE BEGIN RTOS_THREADS */
  /* add threads, ... */
  /* USER CODE END RTOS_THREADS */

  /* USER CODE BEGIN RTOS_EVENTS */
  /* add events, ... */
  /* USER CODE END RTOS_EVENTS */

  /* Start scheduler */
  osKernelStart();

  /* We should never get here as control is now taken by the scheduler */
  /* Infinite loop */
  /* USER CODE BEGIN WHILE */
  while (1)
  {


    /* USER CODE END WHILE */

    /* USER CODE BEGIN 3 */
  }
  /* USER CODE END 3 */
}

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
/* USER CODE BEGIN 4 */
int _write(int file, char *ptr, int len)
{
  (void)file;
  int DataIdx;

  for (DataIdx = 0; DataIdx < len; DataIdx++)
  {
    ITM_SendChar(*ptr++);
  }
  return len;
}


void HAL_GPIO_EXTI_Callback(uint16_t GPIO_Pin) {
	switch(GPIO_Pin)
	{
	case PWR_BUTTON_Pin:
		// reset IDLE timer.
		if (HAL_GetTick() - lastPwrPress > 200) {;
			buttonPressed = POWER;
			lastPwrPress = lastActivity = HAL_GetTick();
			osSemaphoreRelease(buttonPressSemHandle);
		}
		// blink BTTN PRESS LED Twice
		// send UART Command to BLE
		break;
	case MODE_BUTTON_Pin:
		if (HAL_GetTick() - lastModePress > 200) {;
			buttonPressed = MODE;
			lastModePress = lastActivity = HAL_GetTick();
			osSemaphoreRelease(buttonPressSemHandle);
		}
		// blink BTTN PRESS LED Twice
		// send UART Command to BLE
		break;
	case AUTO_DIM_Pin:
		if (HAL_GetTick() - lastAutoDimPress > 200) {;
			buttonPressed = AUTODIM;
			lastAutoDimPress = lastActivity = HAL_GetTick();
			osSemaphoreRelease(buttonPressSemHandle);
		}
		// blink BTTN PRESS LED Twice
		// send UART Command to BLE
		break;
	case ACC_INT_Pin:
//		printf("acc_int_ INTERRUPT!\n"); // avoid printf in RTOS
		if (HAL_GetTick() - lastMotion > 200) {
			lastMotion = lastActivity = HAL_GetTick();
		}
		// send UART Command to BLE
		break;

	}
}

/*
 * Receives bm71 UART responses in background.
 *
 * Although unlikely, rxBuf and rxBufSize could IN THEORY be overwritten by this interrupt
 * while a previous bm71_ParseResponse is running.
 *
 * In future, if this actually becomes an issue, use some sort of circular buffer to
 * avoid contention over the RxBuf and its size.
 */
void HAL_UARTEx_RxEventCallback(UART_HandleTypeDef *huart, uint16_t Size)
{
  if (BM71_GetHandle() == huart) {
	  BM71_SetRxSize(Size);
	  HAL_UARTEx_ReceiveToIdle_IT(BM71_GetHandle(), BM71_GetRxBuf(), 256); // lthough unlikely, rxBuf in theory could be overwritten with bm71 asynch response while in parse function. deal with later, insignificant issue.
	  osSemaphoreRelease(uartRecSemHandle);
  }
}

/* USER CODE END 4 */

/* USER CODE BEGIN Header_StartMainTask */
/**
  * @brief  Function implementing the mainTask thread.
  * @param  argument: Not used
  * @retval None
  */
/* USER CODE END Header_StartMainTask */
void StartMainTask(void *argument)
{
  /* USER CODE BEGIN 5 */
  /* Infinite loop */
  for(;;)
  {

	  if (HAL_GetTick() - lastActivity >= 10000) {

		  	  // sleep user peripherals
		  	  osMutexAcquire(bm71LockHandle, osWaitForever); // wait to avoid sleeping if separate task is modifying bm71 state
			  BM71_Sleep();
			  DRV2605L_Disable();
			  TurnOffAllLED();

			  // disable clocks
			  HAL_SuspendTick();
			  SysTick->CTRL &= ~SysTick_CTRL_TICKINT_Msk; // temporary (else RTOS tick wakes us up)

			  // enter stop mode
			  HAL_PWR_EnterSTOPMode(PWR_MAINREGULATOR_ON, PWR_STOPENTRY_WFI);

			  // enable clocks
			  SystemClock_Config();
			  SysTick->CTRL |= SysTick_CTRL_TICKINT_Msk; // temporary (else RTOS tick wakes us up)
			  HAL_ResumeTick();

			  // wake user peripherals & notify user
			  TurnOnBlueLED();
			  BM71_Wake();
		  	  osMutexRelease(bm71LockHandle); // wait JUST IN CASE a task is affecting internal bm71 state. (will likely never happen).
			  DRV2605L_Enable();
			  DRV2605L_TriggerHaptics(); // needs 250us to accept i2c commands.
			  lastActivity = HAL_GetTick(); // does not include time spent in STOP. fine for our use case.
		  }

		  // check TSC (touch) readings
		  if (tsl_user_Exec() != TSL_USER_STATUS_BUSY) {
		      ProcessTouch();
		  }


	//	  if (bm71_GetStatus() == STANDBY && !bm71_ConnectionPending()) {
	//		  bm71_ConnectToDisplay();
	//	  }

		  // check battery status (could do extra task for this, but RAM usage limited)
		  uint32_t currTime = HAL_GetTick();
		  if (currTime - lastBattCheck > 2000) { // abstract away this timing function into the led driver
			  CheckLowBatt(&hadc1);
			  lastBattCheck = currTime;
		  }
    osDelay(10); // TSC doesn't work properly without some sort of delay. fix later
  }
  /* USER CODE END 5 */
}

/* USER CODE BEGIN Header_StartButtonTask */
/**
* @brief Function implementing the buttonTask thread.
* @param argument: Not used
* @retval None
*/
/* USER CODE END Header_StartButtonTask */
void StartButtonTask(void *argument)
{
  /* USER CODE BEGIN StartButtonTask */
  /* Infinite loop */
  for(;;)
  {
	  // wakes on button press GPIO/EXTI interrupt releasing semaphore.
  	  osSemaphoreAcquire(buttonPressSemHandle, osWaitForever);
  	  osMutexAcquire(bm71LockHandle, osWaitForever); // wait if another task is affecting internal state of bm71
	  if (buttonPressed != NONE) {
		  switch (buttonPressed) { // could make bitmask if dealing  with multiple presses. but presses are fast and sparse. not needed now.
			case MODE:
				BM71_CommandDisplay(COMMAND, 0);
				break;
			case AUTODIM:
				BM71_CommandDisplay(COMMAND, 1); //
				break;
			case POWER:
				BM71_CommandDisplay(COMMAND, 2);//
				break;
			default:
				break;
		}
		osMutexRelease(bm71LockHandle);
		  buttonPressed = NONE;

		  // could implement in separate task, but presses are sparse. works for now, change later if needed.
		  TurnOnBlueLED();
		  osDelay(50); // task sleep 50ms

		  TurnOffBlueLED();
		  osDelay(50);

		  TurnOnBlueLED();
		  osDelay(50);

		  TurnOffBlueLED();
	  }
  }
  /* USER CODE END StartButtonTask */
}

/* USER CODE BEGIN Header_StartUartRecTask */
/**
* @brief Function implementing the uartTask thread.
* @param argument: Not used
* @retval None
*/
/* USER CODE END Header_StartUartRecTask */
void StartUartRecTask(void *argument)
{
  /* USER CODE BEGIN StartUartRecTask */
  /* Infinite loop */
  for(;;)
  {
	// wakes on rxEventISR to releasing semaphore.
	// not too much different from rxReady signal we had in superloop.
	osSemaphoreAcquire(uartRecSemHandle, osWaitForever);
	osMutexAcquire(bm71LockHandle, osWaitForever); // wait if another task is affecting internal state of bm71
    BM71_ParseResponse();
    osMutexRelease(bm71LockHandle);
  }
  /* USER CODE END StartUartRecTask */
}

/**
  * @brief  Period elapsed callback in non blocking mode
  * @note   This function is called  when TIM6 interrupt took place, inside
  * HAL_TIM_IRQHandler(). It makes a direct call to HAL_IncTick() to increment
  * a global variable "uwTick" used as application time base.
  * @param  htim : TIM handle
  * @retval None
  */
void HAL_TIM_PeriodElapsedCallback(TIM_HandleTypeDef *htim)
{
  if (htim->Instance == TIM6) {
    HAL_IncTick();
  }
}

/**
  * @brief  This function is executed in case of error occurrence.
  * @retval None
  */
void Error_Handler(void)
{
  /* USER CODE BEGIN Error_Handler_Debug */
  /* User can add his own implementation to report the HAL error return state */
  __disable_irq();
  while (1)
  {
  }
  /* USER CODE END Error_Handler_Debug */
}

#ifdef  USE_FULL_ASSERT
/**
  * @brief  Reports the name of the source file and the source line number
  *         where the assert_param error has occurred.
  * @param  file: pointer to the source file name
  * @param  line: assert_param error line source number
  * @retval None
  */
void assert_failed(uint8_t *file, uint32_t line)
{
  /* USER CODE BEGIN 6 */
  /* User can add his own implementation to report the file name and line number,
     ex: printf("Wrong parameters value: file %s on line %d\r\n", file, line) */
  /* USER CODE END 6 */
}
#endif /* USE_FULL_ASSERT */

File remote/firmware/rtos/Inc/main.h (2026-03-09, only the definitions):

#define UART_RX_IND_Pin GPIO_PIN_15
#define UART_RX_IND_GPIO_Port GPIOC
#define BATT_ADC_Pin GPIO_PIN_1
#define BATT_ADC_GPIO_Port GPIOA
#define LRA_TRIG_Pin GPIO_PIN_3
#define LRA_TRIG_GPIO_Port GPIOA
#define LRA_EN_Pin GPIO_PIN_4
#define LRA_EN_GPIO_Port GPIOF
#define ACC_INT_Pin GPIO_PIN_0
#define ACC_INT_GPIO_Port GPIOB
#define ACC_INT_EXTI_IRQn EXTI0_IRQn
#define AUTO_DIM_Pin GPIO_PIN_7
#define AUTO_DIM_GPIO_Port GPIOC
#define AUTO_DIM_EXTI_IRQn EXTI9_5_IRQn
#define PWR_BUTTON_Pin GPIO_PIN_8
#define PWR_BUTTON_GPIO_Port GPIOC
#define PWR_BUTTON_EXTI_IRQn EXTI9_5_IRQn
#define MODE_BUTTON_Pin GPIO_PIN_9
#define MODE_BUTTON_GPIO_Port GPIOC
#define MODE_BUTTON_EXTI_IRQn EXTI9_5_IRQn
#define BUTTN_PRESS_LED_Pin GPIO_PIN_11
#define BUTTN_PRESS_LED_GPIO_Port GPIOA
#define LOW_BATT_LED_Pin GPIO_PIN_12
#define LOW_BATT_LED_GPIO_Port GPIOA
#define BLE_MODE_Pin GPIO_PIN_10
#define BLE_MODE_GPIO_Port GPIOC
#define BLE_STATUS1_IND_Pin GPIO_PIN_11
#define BLE_STATUS1_IND_GPIO_Port GPIOC
#define BLE_RST_N_Pin GPIO_PIN_8
#define BLE_RST_N_GPIO_Port GPIOB
#define BLE_STATUS2_IND_Pin GPIO_PIN_9
#define BLE_STATUS2_IND_GPIO_Port GPIOB
#define Haptic_Driver_Address_7BIT 0x5A
#define Haptic_Driver_Address ((0x5A) << 1)

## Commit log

2025-11-26 Rename UM-LED Design Proposal.pdf to UM-LED Initial Design Proposal.pdf
2026-03-09 Add KiCad hardware files for remote (done) and display (beginning)
    [LED.kicad_sch, MCU.kicad_sch, Power.kicad_sch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]
2026-03-09 add firmware files for remote superloop and rtos. changed top levels to remote and display
    [LED.kicad_sch, MCU.kicad_sch, Power.kicad_sch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]

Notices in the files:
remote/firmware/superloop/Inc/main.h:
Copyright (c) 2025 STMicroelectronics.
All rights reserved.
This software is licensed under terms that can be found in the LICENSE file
